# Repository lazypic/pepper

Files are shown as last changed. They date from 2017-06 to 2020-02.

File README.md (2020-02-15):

# Pepper
- 종이로 만드는 노트북 받침대
- Release: version 13

### 프로젝트 목표
- 장시간 노트북 시용 시 목 꺾임, 목디스크 예방
- 간편한 설치, 가벼운 무게(휴대성)
- 개별 부품 수리가능. 잃어버려도 부담이 없을 것
- 12인치 받침대는 종이의 총 면적이 A4용지 사이즈보다 작을 것

### 제작방법
- 준비물 : 칼,칼판,자,연필,지우개,사포,로얄보드 4합2절,백색 개퍼테이프(접힘부분 처리)
- 도면없이 자, 종이로 손쉽게 작업할 수 있는 수치를 사용하려고 노력했습니다.
- 칼질시 손을 조심하세요. 로얄보드 4합2절 종이는 매우 두껍습니다.
- 날카로운 종이의 모서리는 사포질을 해주세요.
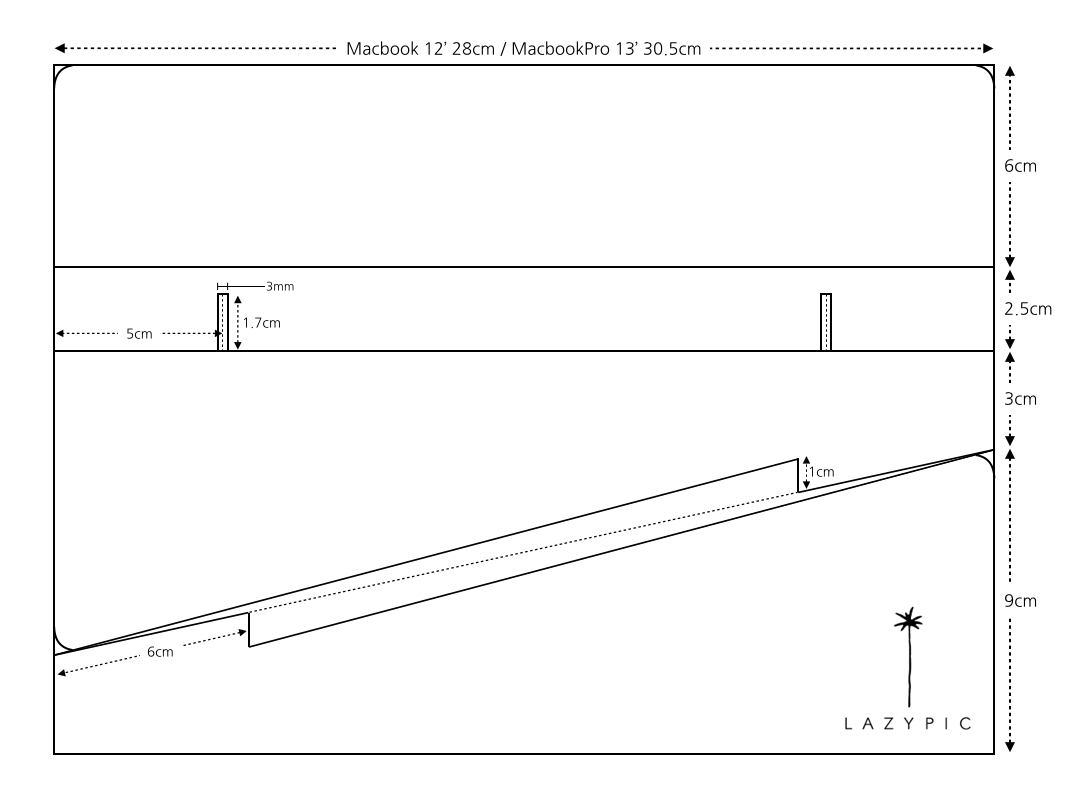
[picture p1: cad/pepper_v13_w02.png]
cad


### Gallery
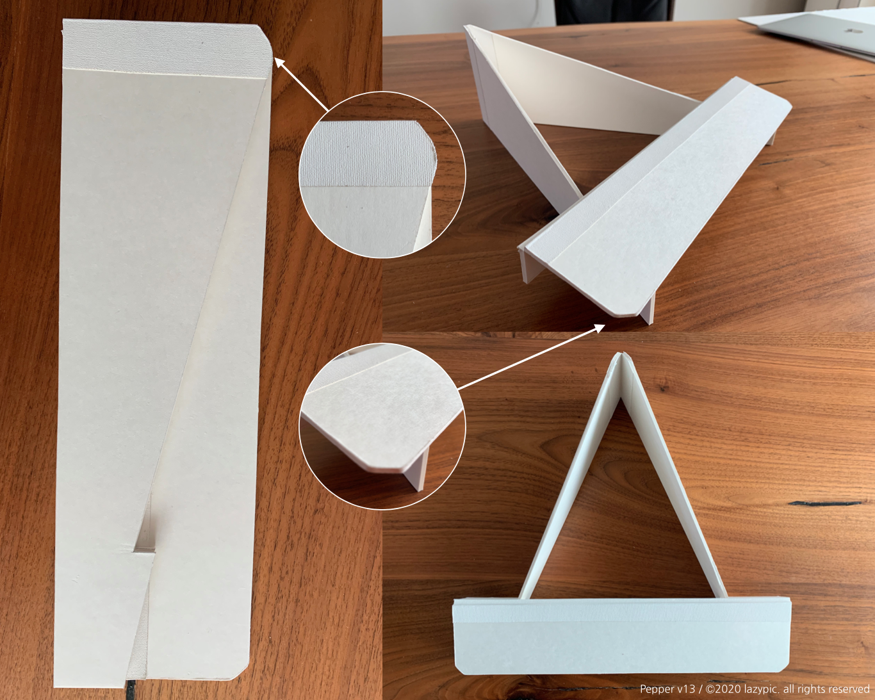
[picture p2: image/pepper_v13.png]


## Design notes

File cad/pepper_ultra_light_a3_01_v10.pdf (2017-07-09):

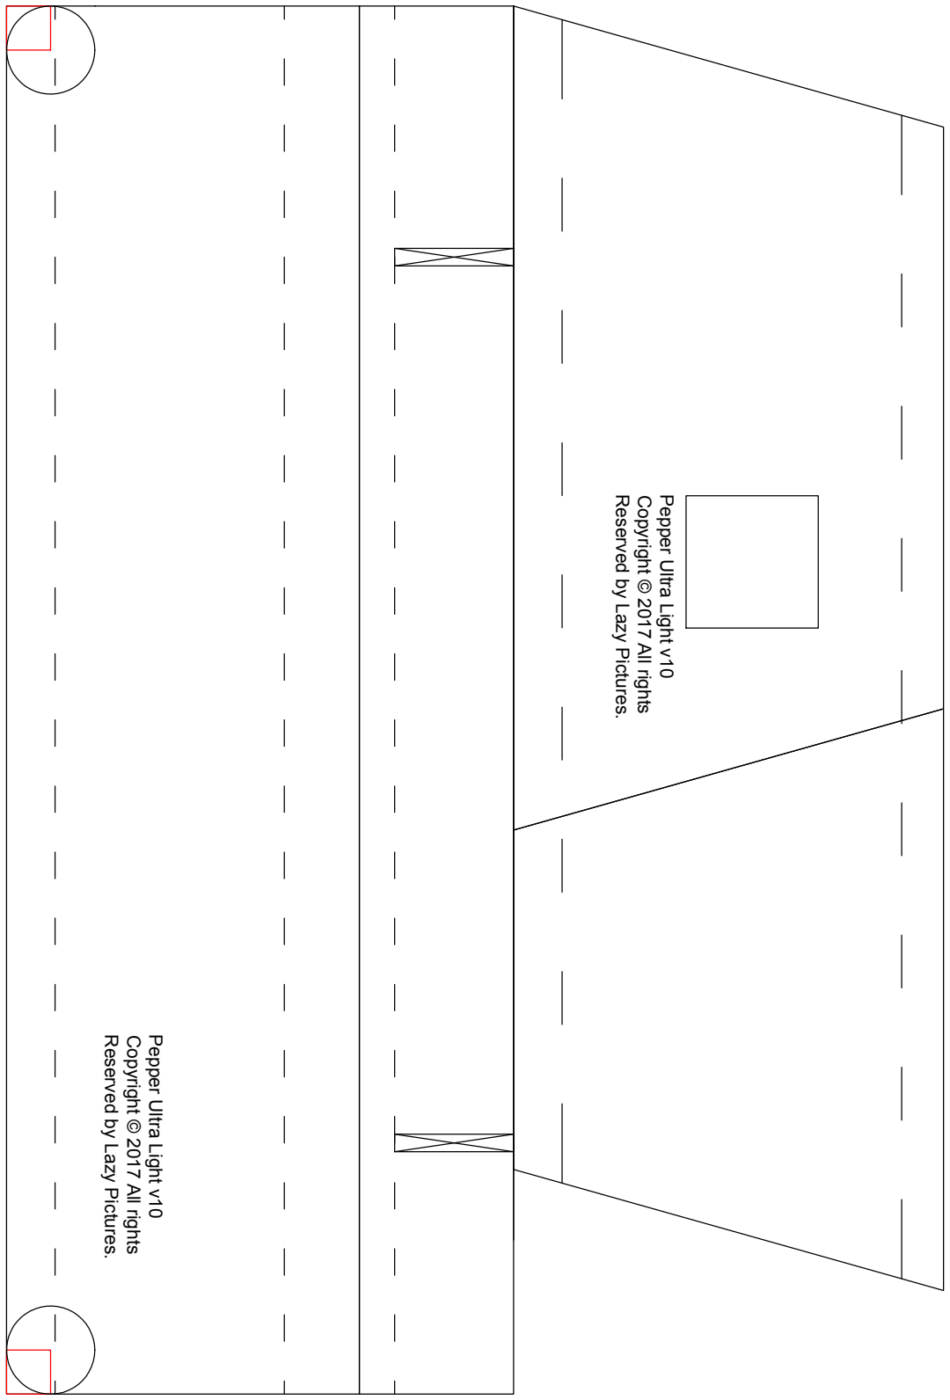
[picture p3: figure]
Reserved by Lazy Pictures.; Copyright © 2017 All rights; Pepper Ultra Light v10

Pepper Ultra Light v10
A3(297x594mm) Page1 Reserved by Lazy Pictures. Copyright © 2017 All rights Pepper Ultra Light v10

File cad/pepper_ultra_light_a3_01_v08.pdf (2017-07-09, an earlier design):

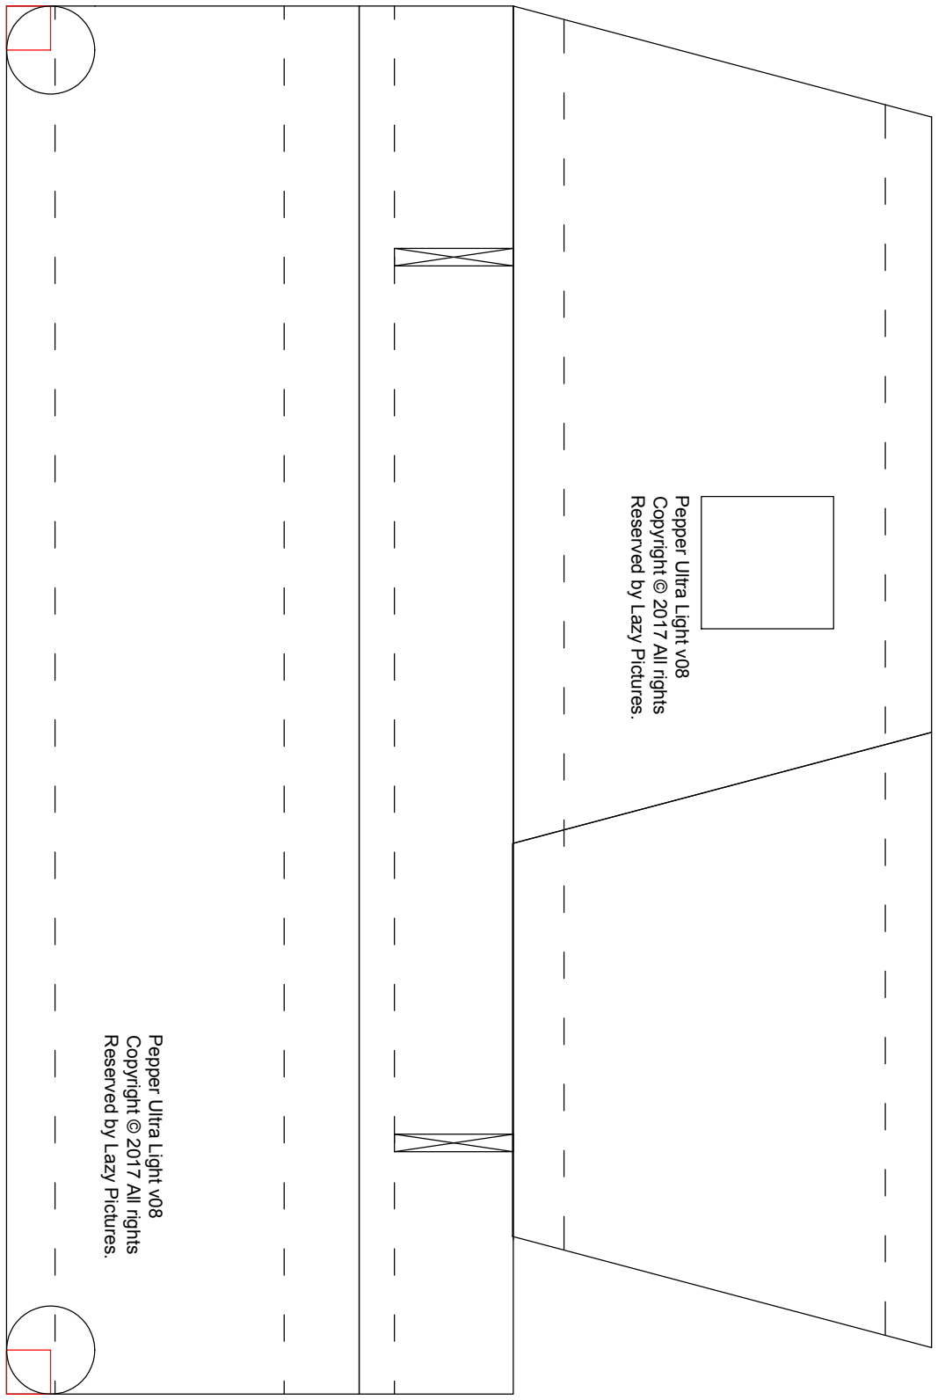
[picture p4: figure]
Reserved by Lazy Pictures.; Copyright © 2017 All rights; Pepper Ultra Light v08

Pepper Ultra Light v08
A3(297x594mm) Page1 Reserved by Lazy Pictures. Copyright © 2017 All rights Pepper Ultra Light v08

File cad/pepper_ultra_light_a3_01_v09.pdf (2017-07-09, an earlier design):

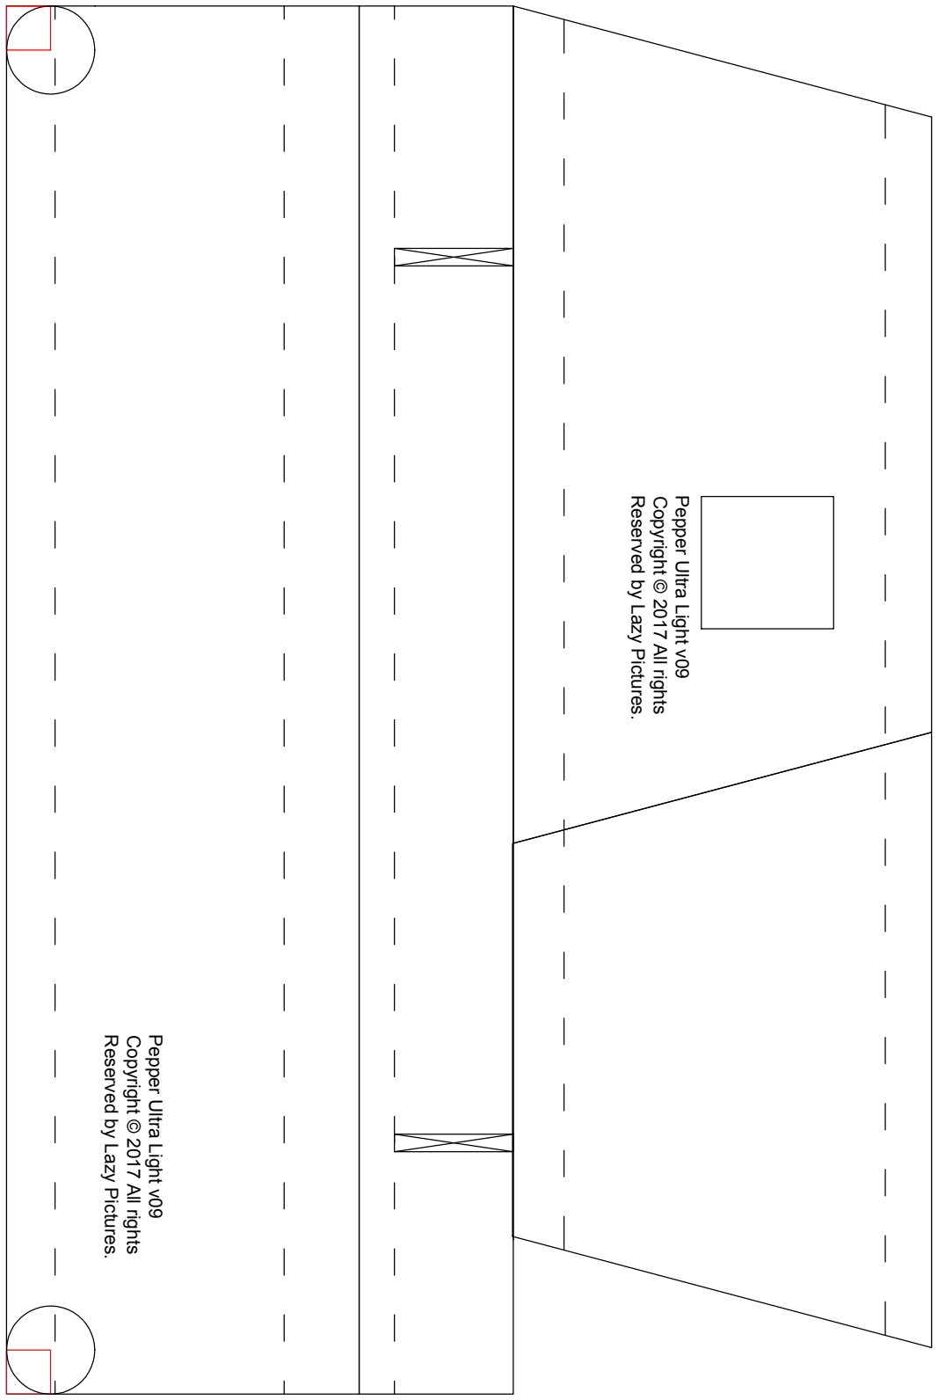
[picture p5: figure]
Reserved by Lazy Pictures.; Copyright © 2017 All rights; Pepper Ultra Light v09

Pepper Ultra Light v09
A3(297x594mm) Page1 Reserved by Lazy Pictures. Copyright © 2017 All rights Pepper Ultra Light v09

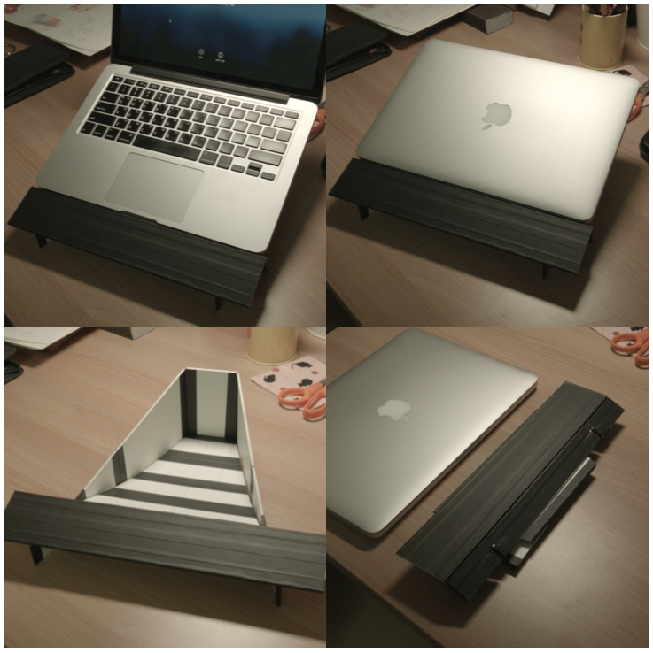
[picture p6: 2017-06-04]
cad/preview_pepper_ultra_light.png

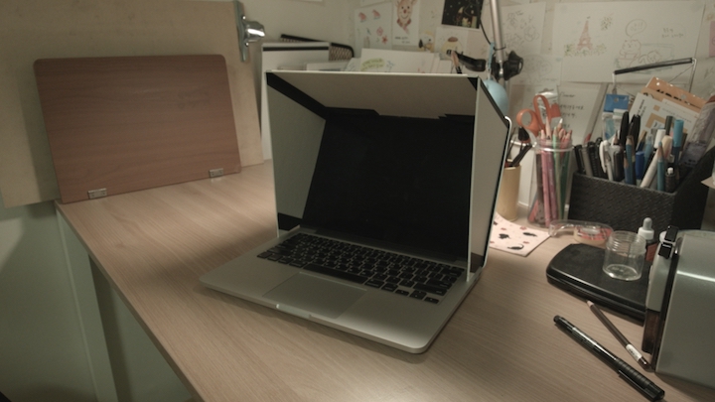
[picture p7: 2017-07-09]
cad/preview_pepper_hood.jpg

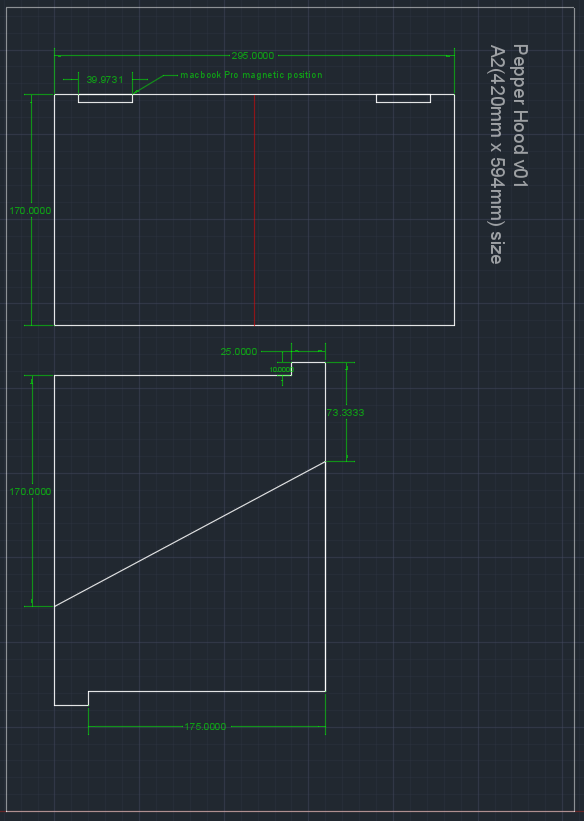
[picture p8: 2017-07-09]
cad/screenshot_pepper_hood.png

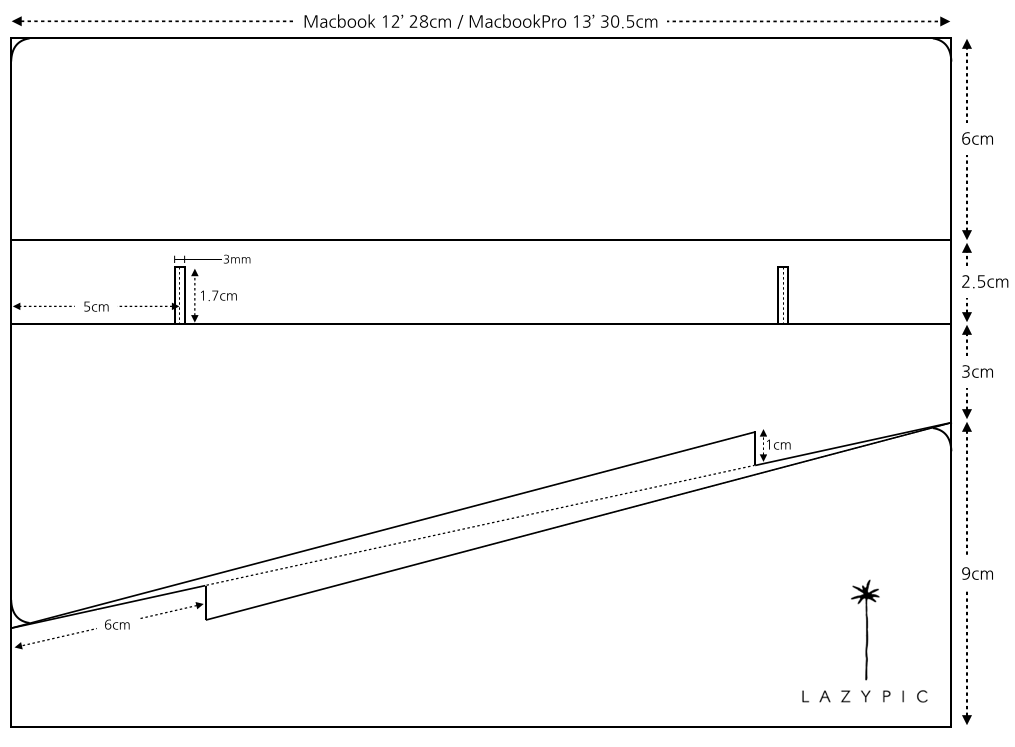
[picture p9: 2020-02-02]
cad/pepper_v13.png

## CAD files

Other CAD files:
cad/pepper_v12.dwg
cad/pepper_ultra_light_v10.dwg
cad/pepper_hood_v02.dwg
cad/pepper_v11.dwg
cad/pepper_ultra_light_v09.dwg
cad/pepper_ultra_light_v07.dwg
cad/pepper_hood_v01.dwg
cad/pepper_ultra_light_v08.dwg

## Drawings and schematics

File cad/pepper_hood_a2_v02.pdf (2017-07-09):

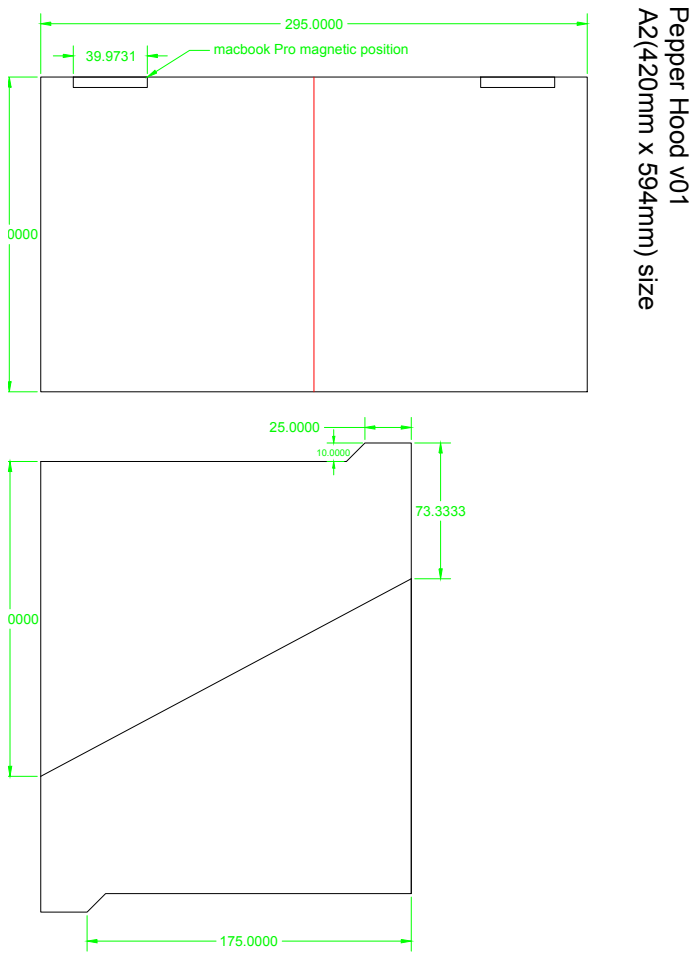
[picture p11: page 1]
Pepper Hood v01; A2(420mm x 594mm) size; macbook Pro magnetic position

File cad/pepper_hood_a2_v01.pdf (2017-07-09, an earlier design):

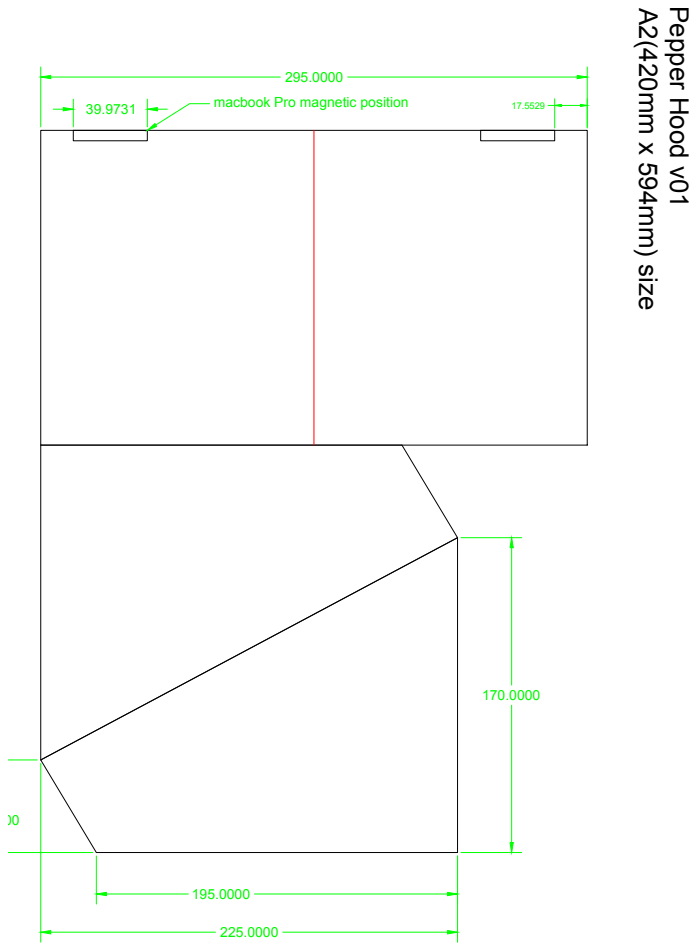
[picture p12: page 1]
Pepper Hood v01; A2(420mm x 594mm) size; macbook Pro magnetic position

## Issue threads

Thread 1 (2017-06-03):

pepper 로고 만들기

yoonjieun, 2017-06-03:

yoonjieun, 2017-06-03:
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

khw7096, 2017-06-29:
역시 다른 로고가 더 잘 어울릴듯. 로고는 페퍼 울트라 라이트 안쪽 정면 사각형 프레임안에 캐드를 이용해서 넣을 예정이다.

khw7096, 2017-07-09:
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

suinbaek, 2017-07-09:
요 ! 13 ?

khw7096, 2017-07-09:
13인치의 줄임말이예용. pepper ultra light가 너무 긴 느낌이 있는데 어떤 이름이 좋을것 같아요?

khw7096, 2017-07-09:
아직 결정을 하기전에 고민하는 중이랄까나까나..

kybin, 2017-07-09:
인치라니!

센치가 국제 표준입니다

khw7096, 2017-07-12:
아직 애플의 세계를 모르시네...ㅋㅋㅋ

khw7096, 2018-07-26:
오 좋은 아이디어예요! 로고가 더 심플해야겠네요. 나중에 칼선 제작을 하려면...

khw7096, 2019-05-13:
다른 제품과 마찬지로 레이지픽 캐릭터 "pepe" 가 담당하여 이 제품을 메니징한다.

khw7096, 2019-09-15:
구멍을 내는 로고의 단점은 개인이 작업하기에는 불편하다. 공장에서 일괄 처리 해야한다.
손쉽게 만드는 방법에서 벗어나는 것 같다.

khw7096, 2019-09-15:
로고는 좋은 아이디어가 발생할 때 다시 이슈로 열겠습니다.

Closed 2019-09-15.

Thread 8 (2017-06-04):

종이공예품처럼 옻칠을 하면 어떨까?

khw7096, 2017-06-04:
http://storefarm.naver.com/15440704/products/429917719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

khw7096, 2017-06-04:
옻칠이 잘된 종이 자체는 15~20만원 정도한다. 좋은 퀄리티로 바르면 받침대의 가치는 45~60만원선으로 생각함.

khw7096, 2017-06-04:
얇게 여러번 발라야한다. 겨울에는 작업을 해도 건조조건이 안된다. 공기, 물, 불 빼고는 모두 칠이 가능하다.

khw7096, 2017-06-04:
종이를 옻칠로 붙여 틀을 만드는 것을 지태칠기라고 한다.

khw7096, 2017-06-04:
레퍼런스 : 무게는 종이, 룩은 옻칠된 나무. 사진은 지태칠기의 재질중하나이다.
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

khw7096, 2017-06-04:
작품성은 올라가지만 막쓸 수 없게될듯... 적용 X

Closed 2017-06-04.

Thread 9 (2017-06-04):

참고자료

khw7096, 2017-06-04:
http://www.ntrexgo.com

khw7096, 2017-06-06:
종이책상 : http://blog.naver.com/bethy_/220220796439

khw7096, 2017-06-06:
트러스트 아치 구조는 A4 두장으로 1.4kg을 버틴다.

khw7096, 2017-06-06:
종이스톨

http://storefarm.naver.com/shanghaimall/products/453966608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

khw7096, 2017-06-06:
오조 그린시트

http://item.gmarket.co.kr/DetailView/Item.asp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

khw7096, 2017-06-06:
종이책상

http://firstsci.co.kr/product/detail.html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

kybin, 2017-06-06:
좋은 레퍼런스들이네요. 특히 refold제품들이 좋은듯. refold라는 이름도 좋구요.

Closed 2017-06-29.

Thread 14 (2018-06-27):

만화로 만들기. 목적, 자연, 종이의 특징을 적기.

khw7096, 2018-06-27:
- 종이로 만들수 있는 물건은 굉장히 많지만 그중 첫번째로 왜 페퍼를 만들었는지 개인감정을 적기.
- 영어로도 적기.

khw7096, 2018-07-01:
아이디어만 있다면 세상의 많은 물건을 종이로 만들 수 있다는것의 메시지를 담기.

khw7096, 2018-07-02:
종이가 썩는 기간은 상황에 따라서 5개월에서~5년정도까지 걸린다.

khw7096, 2019-05-13:
done.

Closed 2019-05-13.

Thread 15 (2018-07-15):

catchphrase 정하기.

khw7096, 2018-07-15:
- protect your neck and nature. : 웅
- save earth save us. : 윤지( help earth, help us를 따라한글임.)
- abnormal flavor paper project : 용빈

khw7096, 2018-07-26:
드디어 참여인가요?!!

kybin, 2018-07-26:
좋네요

kybin, 2018-07-27:
abnormal 보단 unique가 나은것 같아요.

unique flavored projects with paper

khw7096, 2019-09-15:
프로젝트 목표가 catchphrase 보다 중요하다.
Readme.md에 목표를 명확하게 작성함.

Closed 2019-09-15.

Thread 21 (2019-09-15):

도면인쇄, 도면 풀칠없이 만들 수 있는 방안검토(종이 구매 후 자, 칼만 사용)

khw7096, 2019-09-15:

khw7096, 2019-09-15:
손목받침대
- 28cm x 6cm
- 28cm x 2.5cm / 안쪽 3cm 1.7cm 3mm폴 홈.
- 맨끝은 원형으로 잘라준다.

받침
- 26cm x 9cm
- 한쪽변은 3cm
- 변을 따라 5.5cm 지점에서 1cm 아래.

khw7096, 2019-09-15:
긴 자도 필요가 없게되었다. 30cm 자만 있으면 된다.

khw7096, 2020-02-01:
1차 완성.

khw7096, 2020-02-01:
Macbookpro

30.5

Closed 2020-02-02.

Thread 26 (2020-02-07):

레이저 절단.

khw7096, 2020-02-07:
https://m.blog.naver.com/PostView.nhn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

khw7096, 2020-02-07:
- 비용: 초당 15원에서 18원
- 절단속도 180cm / min
- 페퍼도면의 총길이.
- 절단비:개당 1330원 / 전체 244cm정도의 길이이다.
- 1장의 2합4절에서 6개의 페퍼가 나올 수 있다.
- 6개의 페퍼 제작비: 종이 5,000원 + 절단비 8,000(7,980)원 = 13,000원 / 개당 2,166원
- 3000원 미만으로 떨어뜨리는 것은 가능하다.

khw7096, 2020-02-08:
면 프린팅: pepper BI 만들기

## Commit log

2017-05-28 노트북 사이즈 구하기
2017-05-28 내용수정
2017-05-28 알루미늄 도면을 제작시 필요
2017-05-28 설명추가
2017-05-28 오픈소스 캐드링크 추가
2017-06-03 add freeCAD
    [pepper_ultra_light_v01.FCStd]
2017-06-03 부가설명
2017-06-03 설명수정
2017-06-04 도면 업데이트
    [pepper_ultra_light_v01.FCStd, pepper_v02.dwg]
2017-06-04 내용 추가
2017-06-04 유틸리티 추가
2017-06-04 add new cad
    [pepper_v03.dwg]
2017-06-04 이름변경
    [pepper_ultra_light_v03.dwg]
2017-06-04 문방구 추가
2017-06-04 준비물 좀더 추가함
2017-06-04 준비물 추가
2017-06-04 설명다듬기
2017-06-04 가격부분을 확실하게 작성
2017-06-04 목표를 추가함
2017-06-04 도면 v04 업로드
    [pepper_ultra_light_v04.dwg]
2017-06-04 도면수정
    [pepper_ultra_light_v04.dwg]
2017-06-04 라운드 추가
    [pepper_ultra_light_v04.dwg]
2017-06-06 준비물 추가함
2017-06-06 확장자 변경
2017-06-06 원가 표기
2017-06-06 비용 수정
2017-06-06 가격수정
2017-06-06 비용수정
2017-06-06 컨셉추가
2017-06-08 바람이 불때 걸리도록 변경
    [pepper_hood_v02.dwg]
2017-06-08 도면업데이트
    [pepper_hood_v02.dwg]
2017-06-22 add version 5
    [pepper_ultra_light_v05.dwg]
2017-06-22 save as
    [pepper_ultra_light_v05.dwg]
2017-06-24 버전7 추가
    [pepper_ultra_light_v07.dwg]
2017-06-24 단가낮춤
2017-06-24 add v8
    [pepper_ultra_light_v08.dwg]
2017-06-24 필요없는 파일 삭제
    [pepper_ultra_light_v03.dwg, pepper_ultra_light_v04.dwg, pepper_ultra_light_v05.dwg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]
2017-06-29 버전9 추가
    [pepper_ultra_light_v09.dwg]
2017-06-30 단가조정
2017-07-06 add v10
    [pepper_ultra_light_v09.dwg, pepper_ultra_light_v10.dwg]
2017-07-06 세부수정
    [pepper_ultra_light_v10.dwg]
2017-07-09 로고 추가
2017-07-09 로고변경
2017-07-09 설명줄이기
2019-09-15 맞춤법 수정함.
2019-09-15 후드는 활용도가 적다 제거.
2019-10-18 오타수정.
2019-10-18 add v11
    [pepper_v11.dwg]
2019-10-18 캐드버전 추가함. 스크린샷 추가
    [pepper_v12.dwg]
2020-02-02 add other cad
